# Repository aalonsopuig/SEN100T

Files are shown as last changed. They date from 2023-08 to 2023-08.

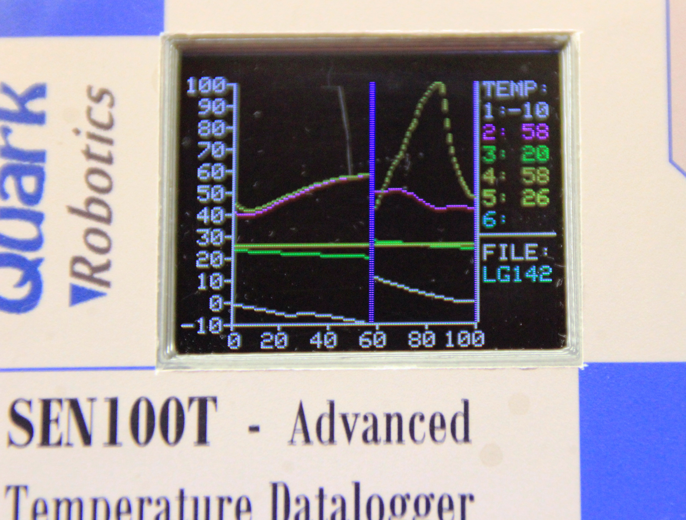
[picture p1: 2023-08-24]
SEN100T_Media/IMG_5914.JPG

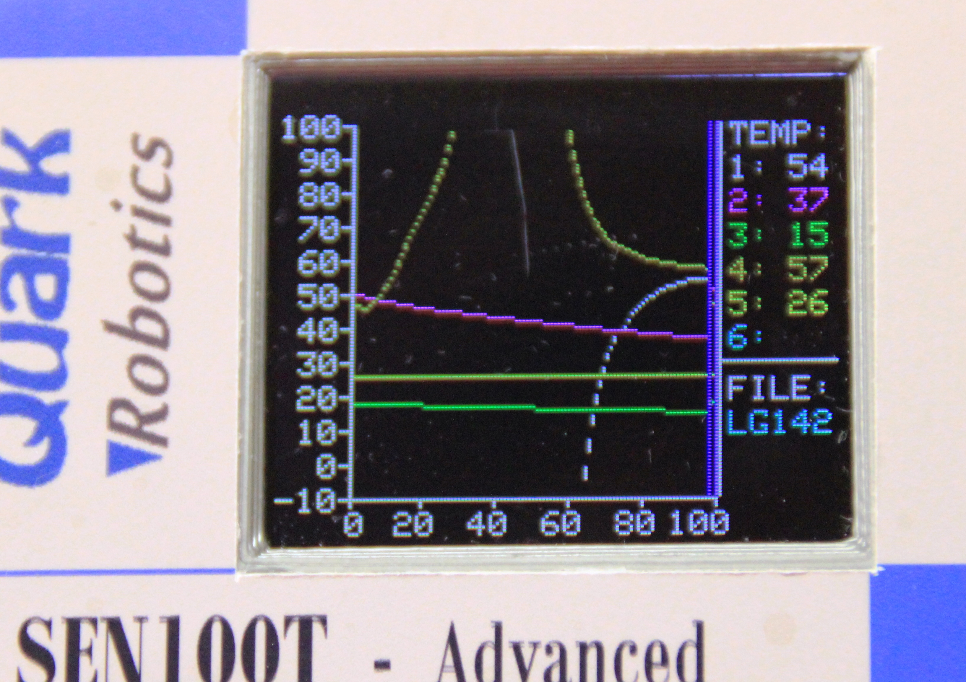
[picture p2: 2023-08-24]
SEN100T_Media/IMG_5920.JPG

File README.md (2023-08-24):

# SEN100T
**Advanced temperature datalogger**

August 2015. Designed by Alejandro Alonso. 
 
---

SEN100T is a compact system, an advanced graphic datalogger for multiple measurement of temperature variations, prepared to measure up to six different temperature points, with values between -55⁰C and 125⁰C, admitting temperature variations of 6⁰C per second. The samples taken are represented on the built-in TFT screen, are stored on removable SD memory and can be transferred via USB in real time. An indispensable instrumentation for laboratories and research departments among others.

This is a fully finished and functional product.



**Specifications**

- Sensors: Up to 6 temperature sensors at the same time. 
- Measurement: -55⁰C to 125⁰C  (Celsius only)
- Precision: 1⁰C
- Max temperature variation response: 6⁰C/sec
- Measurement period: 1sec
- Screen: 1.77" diagonal color TFT screen, with 160 x 128 pixel resolution
- Graphic representation: Up to 6 temperature graphs from -10⁰C to 100⁰C. Samples of up to 100secs
- Datalogging: Removable micro SD card, no sample limit. Format: values separated by commas + time in msec. unlimited number of datalogging files. Sequential file names created in the moment of switching on. - --- Data logged every second.
- Data transfer: Temperature data transferred vía USB. Loadable via terminal. It is possible to use data and produce graphic representations via Excel or other software packages. Data transferred every second.



The product is based on an Arduino Uno board with a custom designed shield, as well as a custom designed case. This repository contains:

- SEN100T_3DBox: 3D cad design of the box (made in Freecad).
- SEN100TT_Caratula: Design of the box label
- SEN100T_Media: Pictures
- SEN100T_Prog:: Arduino program
- Shield_SEN100T: Shield schematic and board design (made in Eagle)

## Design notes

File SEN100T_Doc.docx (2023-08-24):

# SEN100T

# Advance Temperature Datalogger

# Specifications

Sensors: Up to 6 temperature sensors at the same time.

Measurement: -55⁰C to 125⁰C (Celsius only)

Precision: 1⁰C

Max temperature variation response: 6⁰C/sec

Measurement period: 1sec

Screen: 1.77" diagonal color TFT screen, with 160 x 128 pixel resolution

Graphic representation: Up to 6 temperature graphs from -10⁰C to 100⁰C. Samples of up to 100secs

Datalogging: Removable micro SD card, no sample limit. Format: values separated by commas + time in msec. unlimited number of datalogging files. Sequential file names created in the moment of switching on. Data logged every second.

Data transfer: Temperature data transferred vía USB. Loadable via terminal. It is possible to use data and produce graphic representations via Excel or other software packages. Data transferred every second.

# Items included

- Datalogger
- 4Gb SD card
- USB cable
- Power supply
- 6 temperature sensors

# Noticia medios

Quark Robotics S.L. ha sacado al mercado su nuevo sistema compacto SEN100T, datalogger gráfico avanzado para medición múltiple de variaciones de temperatura, preparado para medir hasta seis puntos de temperatura diferentes, con valores entre -55⁰C y 125⁰C, admitiendo variaciones de temperatura de 6⁰C por segundo. Las muestras tomadas de representan en la pantalla TFT incorporada, se almacenan en memoria SD extraíble y pueden ser transferidos vía USB en tiempo real. Una instrumentación indispensable para laboratorios y departamentos de investigación entre otros. Para más información dirigirse a sales@quarkrobotics.com.

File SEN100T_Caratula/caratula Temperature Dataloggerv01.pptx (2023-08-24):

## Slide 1

SEN100T - Advanced Temperature Datalogger

S1
S2
S3
S4
S5
S6

SEN100T - Advanced Temperature Datalogger

S1
S2
S3
S4
S5
S6

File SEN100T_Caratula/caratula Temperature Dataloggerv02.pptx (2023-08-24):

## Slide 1

SEN100T - Advanced Temperature Datalogger

Sensors

Sensors

SEN100T - Advanced Temperature Datalogger

SEN100T - Advanced Temperature Datalogger

Sensors

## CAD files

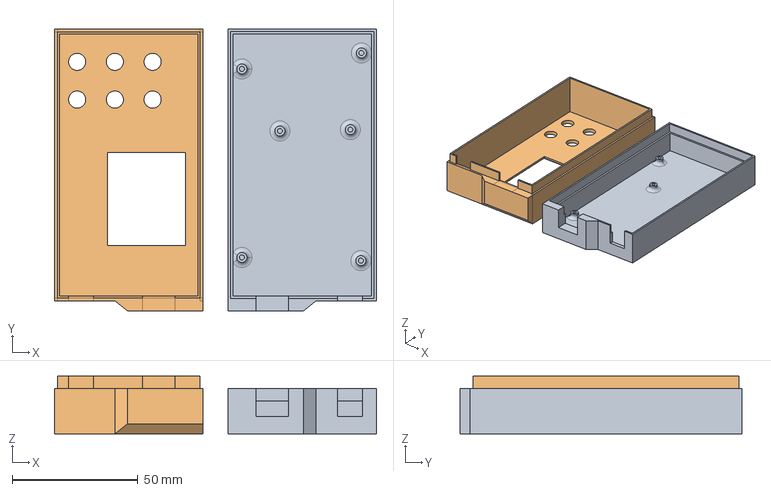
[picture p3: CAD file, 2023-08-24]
SEN100T_3DBox/SEN100T_3DBox_v03.FCStd
128.0 x 112.0 x 23.0 mm
Bot_FINAL
Top_FINAL

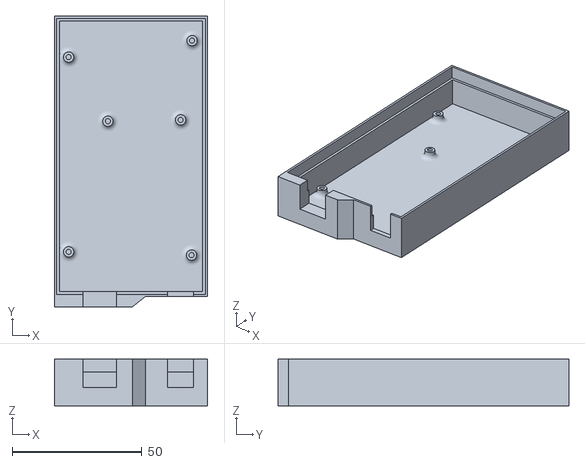
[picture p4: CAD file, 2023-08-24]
SEN100T_3DBox/SEN100T_3DBox_v03_Bot.stl
59.0 x 112.0 x 18.0

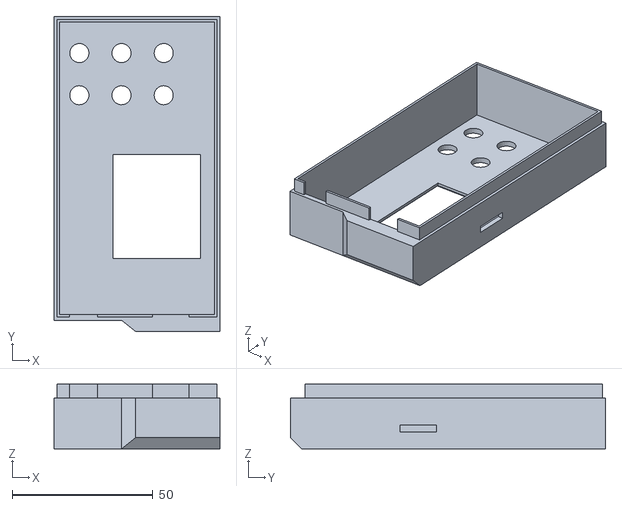
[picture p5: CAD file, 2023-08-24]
SEN100T_3DBox/SEN100T_3DBox_v03_Top.stl
59.0 x 112.0 x 23.0

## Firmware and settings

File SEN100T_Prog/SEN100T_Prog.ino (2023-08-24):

/*
  MultiSense Master
  By Alejandro Alonso
  www.automaconm.blogspot.com
  August 2015
  
  
  

  Credits:
  Screen control is based on code created 15 April 2013 by Scott Fitzgerald   http://www.arduino.cc/en/Tutorial/TFTDisplayText
  Temperature sensors (-55 to 125ºC): http://milesburton.com/Dallas_Temperature_Control_Library
 */


//INCLUDES
#include <TFT.h>     // Arduino LCD library http://www.arduino.cc/en/Reference/TFTLibrary
#include <SPI.h>     // Default library
#include <SD.h>
#include <OneWire.h>
#include <DallasTemperature.h>



//PIN DEFINITIONS
#define SDSelect    4   //Pin selection of SD card
#define Pin_LCD_rst 8   //Pin used by TFT Screen (see http://www.arduino.cc/en/Main/GTFT) 
#define Pin_LCD_dc  9   //Pin used by TFT Screen (see http://www.arduino.cc/en/Main/GTFT)
#define Pin_LCD_cs 10   //Pin used by TFT Screen (see http://www.arduino.cc/en/Main/GTFT)
#define ONE_WIRE_BUS 2  // Temp Data wire is plugged into pin 2 on the Arduino



//OTHER PREPROCESOR
#define FirstFileNum 100           //First number of datalog files
#define LastFileNum 999            //Last number of datalog files. 



//INSTANCES CREATION
TFT     TFTscreen = TFT(Pin_LCD_cs, Pin_LCD_dc, Pin_LCD_rst); // create an instance of the TFT library
File dataFile;
OneWire oneWire(ONE_WIRE_BUS); // Setup a oneWire instance to communicate with any OneWire devices (not just Maxim/Dallas temperature ICs)
DallasTemperature sensors(&oneWire); // Pass our oneWire reference to Dallas Temperature.



//VARIABLES DEFINITION
char          ValuePrintout[5];         // char array to print to the TFT screen
String        ValStr="";             //Used for conversion of integers to string
unsigned long SREAD_CHK_TIME=1000; //Sensors. Time in milliseconds between reading values
unsigned long SRead_time_init;  //sensor measurement timer
unsigned long SRead_time_lapse; //sensor measurement timer
char          LogFileName[12];  //Logs File name
int           Filenum;
int           SensorVal [6];  // sensors values
int           SensorValPrev [6];  // sensors previous values
byte          SensorsNum;  //Number of sensors conected
int           GraphHeight, GraphWidth; //area of graph
int           GraphX0, GraphY0;        //Absolute origin of graph
int           GraphXMax, GraphYMax;        //Max value of X,Y (Absolute)
byte          n;
int           MinY=-10, MaxY=100;  //Min and Max values of Y
int           MinX=0, MaxX=100;    //Min and Max values of X
int           ValX=0;              //Value of X during graph creation



void setup() {

  //TFT Screen
  TFTscreen.begin();   // Screen:
  TFTscreen.background(0, 0, 0);   // clear the screen with a black background

  //SD CARD SETUP
  SD.begin(SDSelect);
  //File name format: LGxxx.txt, where xxx is a consecutive number.
  for (Filenum = FirstFileNum; Filenum <= LastFileNum; Filenum++) {
    //Decide wich will be the file name
    sprintf(LogFileName, "LG%03d.txt", Filenum);
    if(!SD.exists(LogFileName)) {
      Filenum=LastFileNum+1;  //To go out of FOR
    }
  }
  dataFile = SD.open(LogFileName, FILE_WRITE);
  if (dataFile) {
    dataFile.println("Ms, S1, S2, S3, S4, S5, S6");
    dataFile.close();
  }

  //SERIAL PORT SETUP
  Serial.begin (9600);

  //Dallas Temp ssensor
  sensors.begin(); // IC Default 9 bit. If you have troubles consider upping it 12. Ups the delay giving the IC more time to process the temperature measurement
  SensorsNum=sensors.getDeviceCount(); //Identify number of sensosrs connected
  
  //Other
  SRead_time_init = millis();
  
  //Graph
  GraphX0=21;
  GraphY0=TFTscreen.height()-13;
  GraphXMax=TFTscreen.width()-35;
  GraphYMax=5;
  GraphHeight=abs(GraphYMax-GraphY0);
  GraphWidth=abs(GraphXMax-GraphX0);
  TFTscreen.setTextSize(1);  // set the font size
  
  //Graph frame
  SetColor(0);
  TFTscreen.line (GraphXMax+1,GraphY0,GraphXMax+1,GraphYMax);  //Line between graph and data
  TFTscreen.text("TEMP:", GraphXMax+4, 5);  
  TFTscreen.line (GraphXMax+1,75,TFTscreen.width(),75);      //Line between sensor data and other data
  TFTscreen.text("FILE:", GraphXMax+4, 80);  
  SetColor(5);
  TFTscreen.text(LogFileName, GraphXMax+4, 90);  // Log file name

  //X Axis
  SetColor(0);
  TFTscreen.line (GraphX0,GraphY0,GraphXMax,GraphY0);  //X axis
  for (n=0;n<6;n++) {
    TFTscreen.line (GraphX0+n*GraphWidth/5,GraphY0,GraphX0+n*GraphWidth/5,GraphY0+3);
    FormatData(map(n,0,5,MinX,MaxX));
    TFTscreen.text(ValuePrintout, GraphX0+n*GraphWidth/5-13, GraphY0+4);  // Write label
  }
  
  //Y Axis
  TFTscreen.line (GraphX0,GraphY0,GraphX0,GraphYMax);  //Y axis
  for (n=0;n<12;n++) {
    TFTscreen.line (GraphX0-3,GraphY0-n*GraphHeight/11,GraphX0,GraphY0-n*GraphHeight/11);
    FormatData(map(n,0,11,MinY,MaxY));
    TFTscreen.text(ValuePrintout, 0, GraphY0-n*GraphHeight/11-3);  // Write label
  }


  //Print labels
  SetColor(0);   // set the font color
  TFTscreen.text("1:", GraphXMax+4, 15);  // Write label
  SetColor(1);   // set the font color
  TFTscreen.text("2:", GraphXMax+4, 25);  // Write label
  SetColor(2);   // set the font color
  TFTscreen.text("3:", GraphXMax+4, 35);  // Write label
  SetColor(3);   // set the font color
  TFTscreen.text("4:", GraphXMax+4, 45);  // Write label
  SetColor(4);   // set the font color
  TFTscreen.text("5:", GraphXMax+4, 55);  // Write label
  SetColor(5);   // set the font color
  TFTscreen.text("6:", GraphXMax+4, 65);  // Write label
}

void loop() {

  if (millis() < SRead_time_init) SRead_time_init = millis(); // Verify overflow of millis
  else {
    SRead_time_lapse = millis() - SRead_time_init;
    if (SRead_time_lapse > SREAD_CHK_TIME) {
      SRead_time_init = millis();

      //SENSORS READINGS  
     sensors.requestTemperatures(); // Send the command to get temperatures
     for (n=0;n<SensorsNum;n++) {
        SensorVal[n]=sensors.getTempCByIndex(n);
        //Sensor limits
        if (SensorVal[n]<-55) SensorVal[n]=-55;
        if (SensorVal[n]>125) SensorVal[n]=125;
     }

 
      ShowTempValues();  //Show the Temp Values at the right of screen
      DrawTempGraph();   //Draw the line graphs

      //LOG FILE DATA SAVING
      String dataString = String(millis());
     for (n=0;n<SensorsNum;n++) {
        dataString += ",";
        if (SensorVal[n]==-55) 
          dataString +='NC';      //A sensor has been disconected
        else                   
          dataString += String(SensorVal[n]);
      }
    
      // open the file. note that only one file can be open at a time,
      // so you have to close this one before opening another.
      dataFile = SD.open(LogFileName, FILE_WRITE);
    
      // if the file is available, write to it:
      if (dataFile) {
        dataFile.println(dataString);
        dataFile.close();
      }
      //if the file isn't open, pop up an error:
      else {
        SetColor(7);
        TFTscreen.text(LogFileName, GraphXMax+4, 90);  // Log file name
        SetColor(5);
        TFTscreen.text("No SD", GraphXMax+4, 90);  
      }
    // print to the serial port too:
    Serial.println(dataString);

     for (n=0;n<SensorsNum;n++) {
      SensorValPrev[n]=SensorVal[n];
      }
      ValX++;  
      if (ValX>MaxX) ValX=MinX;  //reached end of X. Restart again
    }
  }
}

void FormatData(int NumData)
//Convert a number to an array of chars (ValuePrintout[]), aligned to the right 
//in the three first positions. Example: -1 -> " -1  "
{
    ValStr=String(NumData);
    ValStr.toCharArray(ValuePrintout, 5);  // convert the reading to a char array
    //Align right
    if (ValuePrintout[1]==NULL) {
      ValuePrintout[2]=NULL;
      ValuePrintout[1]=ValuePrintout[0];
      ValuePrintout[0]=' ';
    }
    if (ValuePrintout[2]==NULL) {
      ValuePrintout[2]=ValuePrintout[1];
      ValuePrintout[1]=ValuePrintout[0];
      ValuePrintout[0]=' ';
    }
}

void SetColor(byte color)
//Set a color value between a set of predefined colors
{
  switch (color) {
    case 0:  
      TFTscreen.stroke(255,255,255);   // white
      break;
    case 1:  
      TFTscreen.stroke(255, 51,255);   // magenta
      break;
    case 2:  
      TFTscreen.stroke(0, 255, 0);   // green
      break;
    case 3:  
      TFTscreen.stroke(255,204,0);   // orange
      break;
    case 4:  
      TFTscreen.stroke(255, 255, 0);   // yellow
      break;
    case 5:  
      TFTscreen.stroke(0, 255, 255);   // light blue
      break;
    case 6:  
      TFTscreen.stroke(0, 0, 255);   // dark blue
      break;
    case 7:  
      TFTscreen.stroke(0, 0, 0);   // black
      break;
    case 8:  
      TFTscreen.stroke(255, 0, 0);   // red
      break;
  }
}
void ShowTempValues(){
  //Show the temperature values at the right of the screen
  
//  TFTscreen.background(0, 0, 0);   // clear the screen with a black background


  for (byte index=0;index<SensorsNum;index++) {
  
    //Delete previous value if different
    if (SensorValPrev[index]!=SensorVal[index]) {
      FormatData(SensorValPrev[index]);
      SetColor(7);   // set the font color to black (delete)
      TFTscreen.text(ValuePrintout, GraphXMax+15, index*10+15);   // print the sensor value again to delete
    }

    SetColor(index); //Set color
    
    //Print new value 
    if (SensorVal[index]!=-55) { //No sensor has been disconected
      FormatData(SensorVal[index]);
      TFTscreen.text(ValuePrintout, GraphXMax+15, index*10+15);   // print the sensor value
    }    
  }
}

void DrawTempGraph()
//Draw the temperatures graph
{
  if (ValX>1)
  {
    //Clear area where we are going to draw graph
    SetColor(7);   // set color to black
    TFTscreen.fill(0,0,0); //set the fill color to black
    TFTscreen.rect(map(ValX-1,MinX,MaxX,GraphX0,GraphXMax), GraphYMax,
         map(ValX,MinX,MaxX,GraphX0,GraphXMax)-map(ValX-1,MinX,MaxX,GraphX0,GraphXMax), abs(GraphYMax-GraphY0));

    //Cursor Line
    if (ValX<MaxX) {
      SetColor(6);   // set color to blue
      TFTscreen.line(map(ValX+1,MinX,MaxX,GraphX0,GraphXMax), GraphY0,
                     map(ValX+1,MinX,MaxX,GraphX0,GraphXMax), GraphYMax);
    }
         
    //Sensors graph
    for (byte index=0;index<SensorsNum;index++) {
        SetColor(index);   // set color 
        if ((SensorVal[index]<=MaxY)&&(SensorVal[index]>=MinY)&&(SensorValPrev[index]<=MaxY)&&(SensorValPrev[index]>=MinY)) {
          TFTscreen.line(map(ValX-1,MinX,MaxX,GraphX0,GraphXMax), map(SensorValPrev[index],MinY,MaxY,GraphY0,GraphYMax),
                         map(ValX  ,MinX,MaxX,GraphX0,GraphXMax), map(SensorVal[index]    ,MinY,MaxY,GraphY0,GraphYMax));
        }
    }
  }    
}
